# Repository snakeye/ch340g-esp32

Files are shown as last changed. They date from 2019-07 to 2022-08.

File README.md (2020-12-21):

# CH340G programmer for ESP8266/ESP32

Programming device for ESP8266/ESP32 microcontrollers with proper BOOT/RST cirquitry and +3.3V power output.

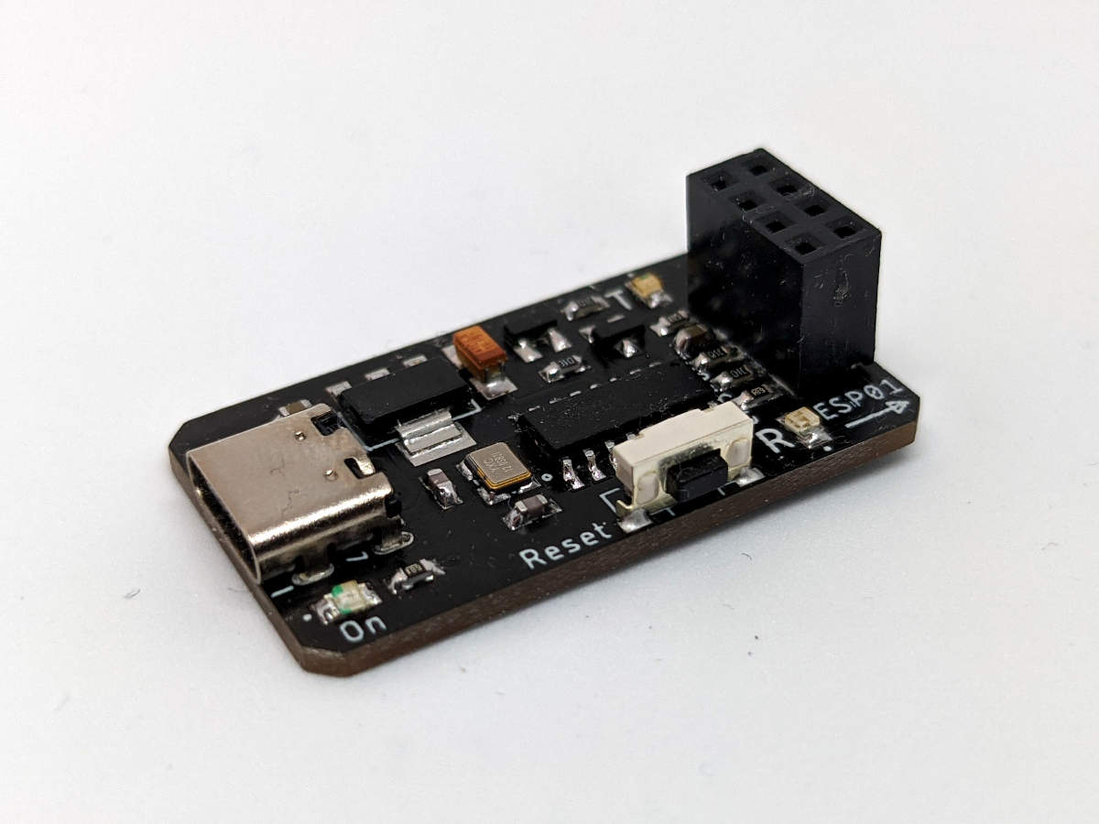
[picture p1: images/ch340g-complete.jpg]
Completed device


More info in my blog [https://en.ovcharov.me/2019/08/16/ch340g-programmer-for-esp8266-esp32/](https://en.ovcharov.me/2019/08/16/ch340g-programmer-for-esp8266-esp32/).

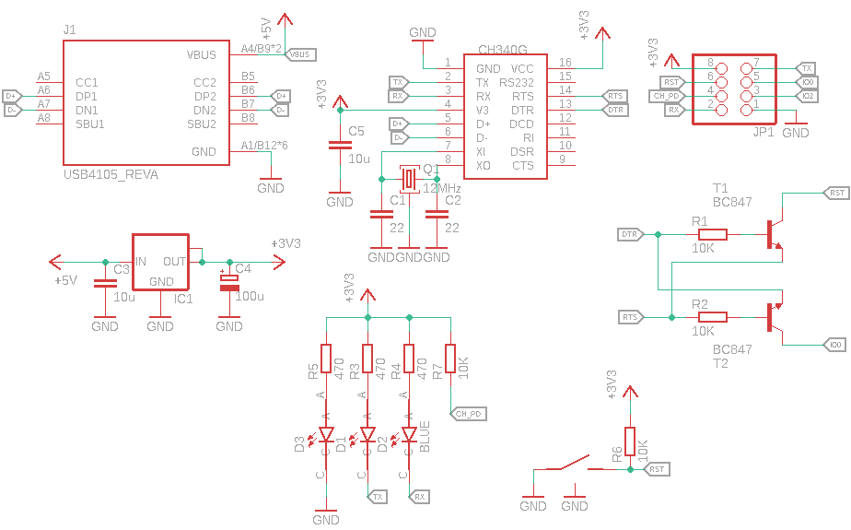
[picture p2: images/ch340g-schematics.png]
Schematics


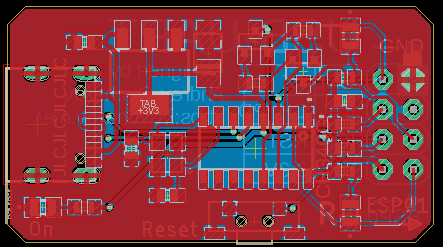
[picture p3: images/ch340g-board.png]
Board


## Update log

**Updated 2020/12/21** Added USB Type C connector and changed header pinout for compatibility with ESP01e

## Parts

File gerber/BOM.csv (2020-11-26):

Comment | Designator | Footprint | LCSC Part #
 | IC1 | SOT223 | C6186
100u | C4 | B/3528-21W | C16133
10K | R1, R2, R6, R7 | R0603 | C99198
10u | C3, C5 | C0603 | C19702
12MHz | Q1 | SMD3225 | C9002
22 | C1, C2 | C0603 | C1653
470 | R3, R4, R5 | R0603 | C177340
BC847 | T1, T2 | SOT23 | C397577
BLUE | D1, D2 | LED0805 | C2293
CH340G | U1 | SOIC16 | C14267
GREEN | D3 | LED0805 | C2296
TS36CA-0.7 | BTN1 | SMD | C412365
USB4105_REVA | J1 | GCT_USB4105_REVA | C319148

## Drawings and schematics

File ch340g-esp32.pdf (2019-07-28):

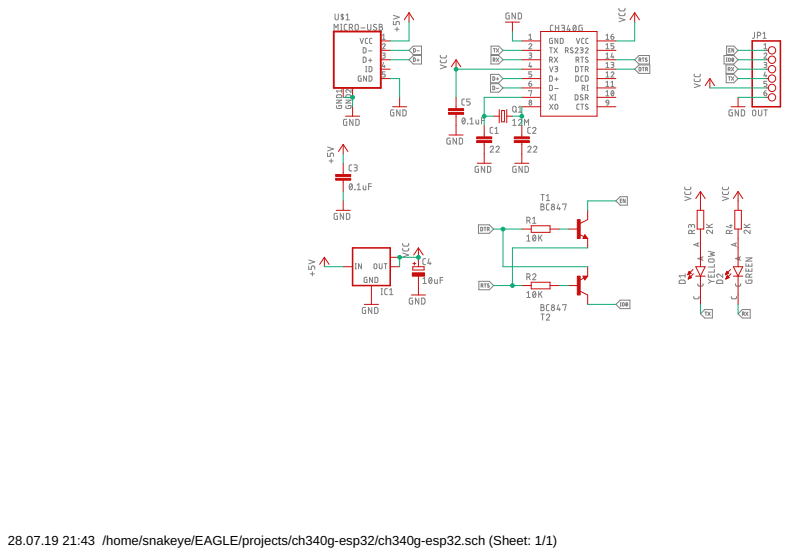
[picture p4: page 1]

28.07.19 21:43 /home/snakeye/EAGLE/projects/ch340g-esp32/ch340g-esp32.sch (Sheet: 1/1)

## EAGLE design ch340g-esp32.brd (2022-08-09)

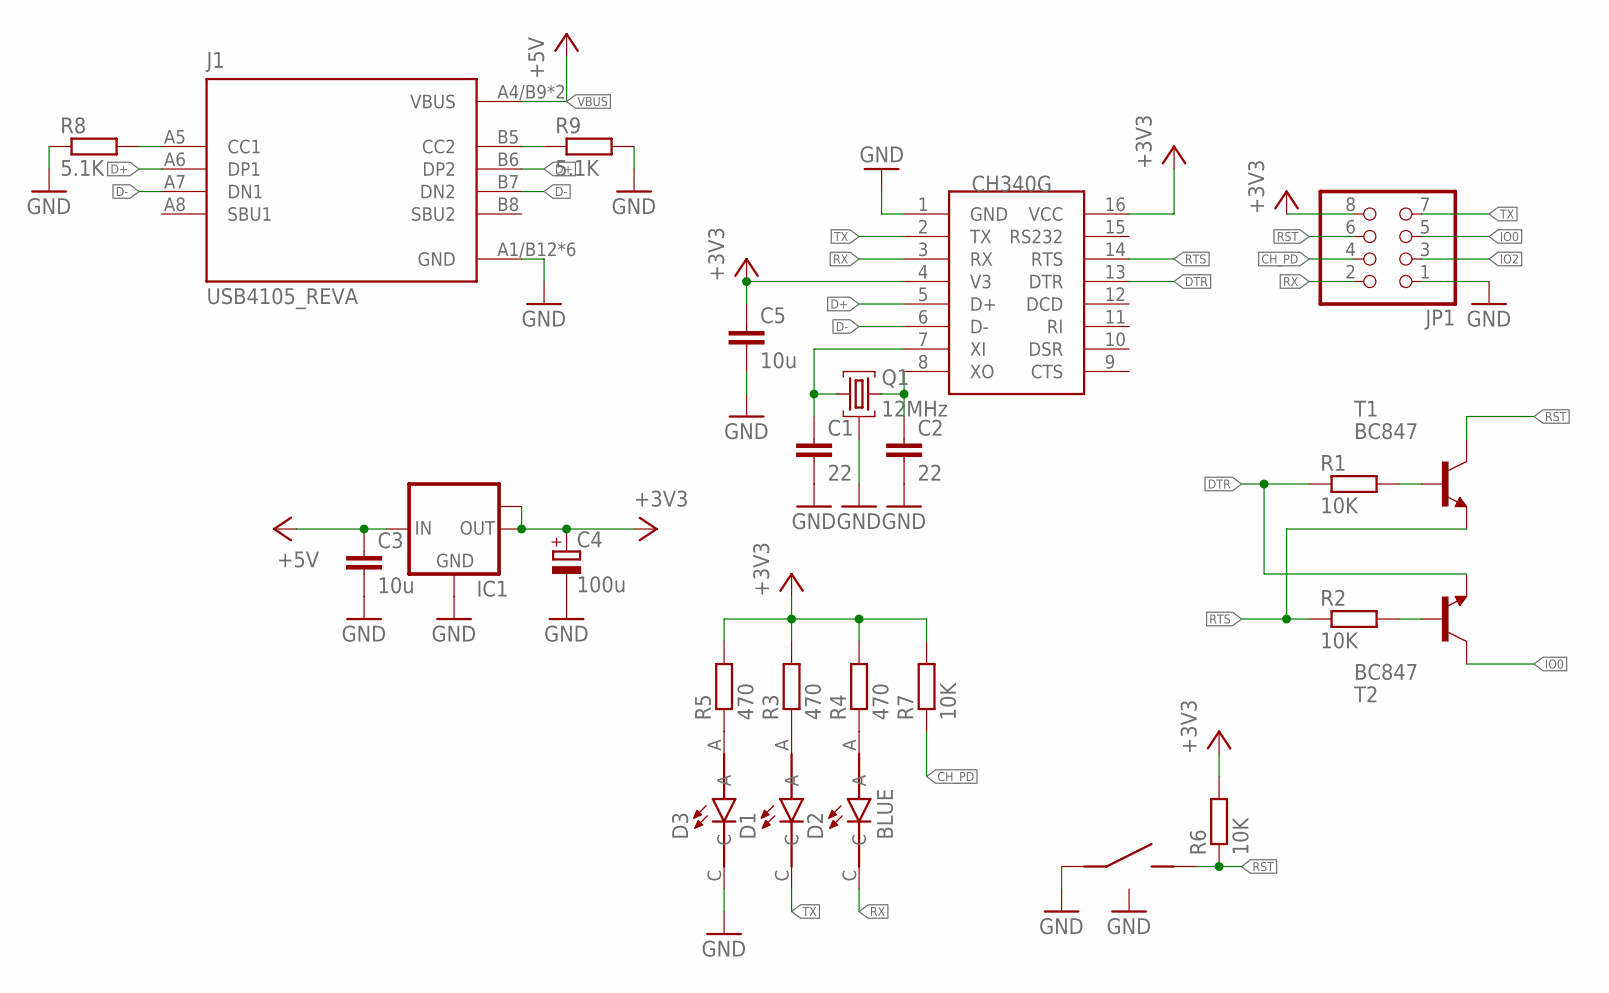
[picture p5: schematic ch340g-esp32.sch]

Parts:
BTN1: TS36CA-0.7; SMD
C1, C2: 22; C0603
C3, C5: 10u; C0603
C4: 100u; B/3528-21W
D1, D2: BLUE; LEDC2012X70N
D3: GREEN; LEDC2012X70N
IC1: LM1117MPX-3.3; SOT223
J1: USB4105_REVA; GCT_USB4105_REVA
JP1: PINHD-2X4; 2X04
Q1: 12MHz; SMD3225
R1, R2, R6, R7: 10K; R0603
R3, R4, R5: 470; R0603
R8, R9: 5.1K; R0603
T1, T2: BC847; SOT23
U1: CH340G; SOIC16

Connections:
+3V3: C4.+, C5.1, IC1.2 (OUT), IC1.TAB (OUT1), JP1.8, R3.2, R4.2, R5.2, R6.2, R7.2, U1.4 (V3), U1.16 (VCC)
CH_PD: JP1.4, R7.1
D+: J1.A6 (DP1), J1.B6 (DP2), U1.5 (D+)
D-: J1.A7 (DN1), J1.B7 (DN2), U1.6 (D-)
DTR: R1.1, T2.2 (E), U1.13 (DTR)
GND: BTN1.A (CASE), BTN1.B (CASE), BTN1.C, C1.2, C2.2, C3.2, C4.-, C5.2, D3.C, IC1.1 (GND), J1.A1/B12 (GND), J1.B1/A12 (GND), J1.G1 (GND), J1.G2 (GND), J1.G3 (GND), J1.G4 (GND), JP1.1, Q1.P$2 (CASE), Q1.P$4 (CASE), R8.1, R9.2, U1.1 (GND)
IO0: JP1.5, T2.3 (C)
IO2: JP1.3
unnamed: C2.1, Q1.P$3 (2), U1.8 (XO)
unnamed: C1.1, Q1.P$1 (1), U1.7 (XI)
unnamed: R1.2, T1.1 (B)
unnamed: R2.2, T2.1 (B)
unnamed: D1.A, R3.1
unnamed: D3.A, R5.1
unnamed: J1.A5 (CC1), R8.2
unnamed: J1.B5 (CC2), R9.1
unnamed: D2.A, R4.1
RST: BTN1.D, JP1.6, R6.1, T1.3 (C)
RTS: R2.1, T1.2 (E), U1.14 (RTS)
RX: D2.C, JP1.2, U1.3 (RX)
TX: D1.C, JP1.7, U1.2 (TX)
VBUS: C3.1, IC1.3 (IN), J1.A4/B9 (VBUS), J1.B4/A9 (VBUS)

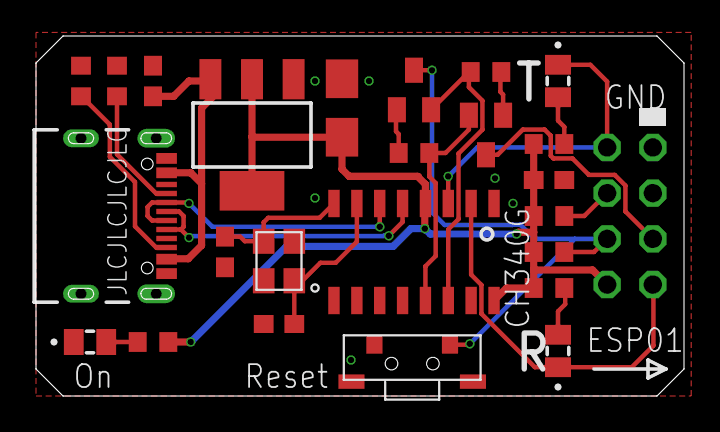
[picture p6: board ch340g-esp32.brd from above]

Board: 2 copper layers, 36.0 x 20.0 mm, 25 parts (1 on the bottom side), 21 nets.

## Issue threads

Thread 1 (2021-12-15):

The board isn't powered if using a USB-C to USB-C cable

MarcelKr, 2021-12-15:
When using a USB-Type-C to USB-Type-C cable to connect the board to the host, the board isn't powered. Using USB-Type-C to USB-A cable it works.

The proper circuitry on CC1 and CC2 is missing for letting the host know to provide 5V.

The circuit could look something like this. Taken from one of my projects having a circuitry for flashing a ESP32. Works fine there.
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

snakeye, 2021-12-15:
Oh, thank you very much for the update! I'm not using USB-C to USB-C cables myself so I missed this point. I'll update design shortly.

street-grease-coder, 2022-07-08:
was it updated though?

snakeye, 2022-07-09:
@street-grease-coder Sorry, not yet. Life has been quite busy for me the last few months.

snakeye, 2022-08-09:
Fixed in the last commit.

Closed 2022-08-09.

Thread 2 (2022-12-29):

5V VS 3.3V

MikeA1s, 2022-12-29:
Me thinks this schematics is wrong. Me thinks this is more accurarte.
https://pcbartists.com/design/embedded/esp32-ch340-programmer-schematic/

snakeye, 2022-12-29:
On this schematics, the CH340G is working in 5V mode. I would expect 5V on the TX line as well as on EN and IO lines. The ESP32 won't die probably but it does not look good to me.

MikeA1s, 2022-12-29:
yes and thank you... but you are supplying 5v to data pins on ch340g..data sheet says..."When using 3.3V
power voltage, connects V3 with VCC, and input 3.3V power voltage. And the other circuit voltage which is
connected with CH340 is no more than 3.3V" Is there a risk of damaging the ch340g.

snakeye, 2022-12-30:
I'm not getting the idea about 5V in the circuit. Everything is powered with 3.3V

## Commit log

2019-07-28 schematic pdf
2019-10-27 board update
    [ch340g-esp32.brd, ch340g-esp32.sch]
2020-01-06 Added schematics image to README.md
2020-11-26 USB TypeC connector; Smaller board
    [ch340g-esp32.brd, ch340g-esp32.sch]
2020-11-26 Production files
    [BOM.csv, ch340g-esp32.brd, ch340g-esp32.sch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]
2020-12-03 Small improvements
    [ch340g-esp32.brd]
2022-08-09 Added support for powering from USB Cable
    [ch340g-esp32.brd, ch340g-esp32.sch]
